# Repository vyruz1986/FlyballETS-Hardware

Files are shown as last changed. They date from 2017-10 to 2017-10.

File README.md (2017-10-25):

## FlyballETS-Hardware

The FlyballETS-Hardware project is a subproject of the [Flyball ETS project](https://www.sparkydevices.com/tag/flyball-ets/).
It contains the designs for the electronic hardware which is required to build the Flyball-ETS project.

## Design Files

The design files are in Eagle format, and consist of several files:
* FlyballETS-Board.sch/brd: Schematic and board file for the PCB of Flyball ETS
* FlyballETS-Board-BOM.txt: Bill of materials used to know which components to order and where to solder them on the board

These files can be used by people who want to improve or change the design.

## Export Files
`Exports/FlyballETS-Board-BRD/SCH.png` are picture exports of the design files so people can view them without needing to install EAGLE

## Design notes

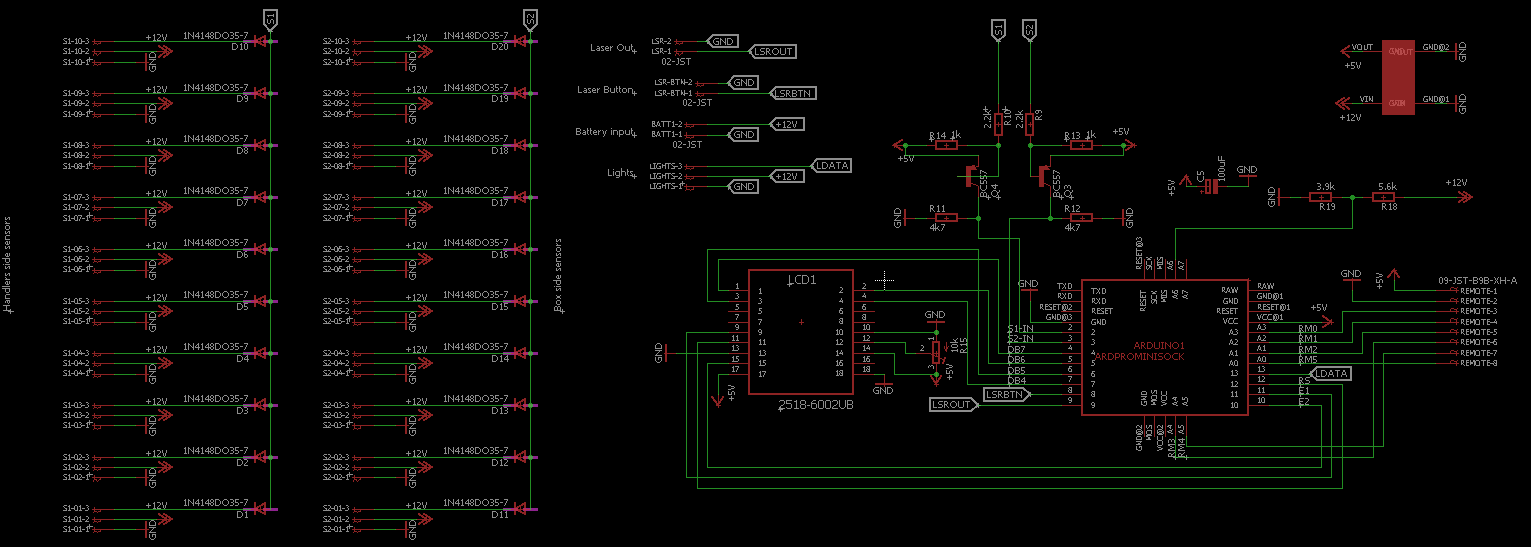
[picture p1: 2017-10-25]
Exports/FlyballETS-Board-SCH.png

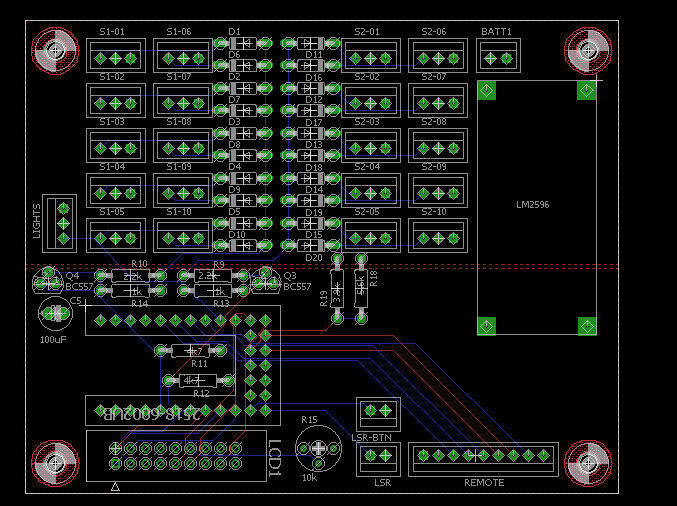
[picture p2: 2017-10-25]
Exports/FlyballETS-Board-BRD.png

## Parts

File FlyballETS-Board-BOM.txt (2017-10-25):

Partlist exported from C:/Workspaces/personal/FlyballETS-Hardware/FlyballETS-Board.sch at 25/10/2017 10:56

Part     Value           Device          Package        Description                          
ARDUINO1 ARDPROMINISOCK  ARDPROMINISOCK  ARDPROMINISOCK                                      
BATT1    02-JST          02-JST          B2B-XH         JST CONNECTOR                        
C5       100uF           CPOL-EUE2,5-6E  E2,5-6E        POLARIZED CAPACITOR, European symbol 
D1       1N4148DO35-7    1N4148DO35-7    DO35-7         DIODE                                
D2       1N4148DO35-7    1N4148DO35-7    DO35-7         DIODE                                
D3       1N4148DO35-7    1N4148DO35-7    DO35-7         DIODE                                
D4       1N4148DO35-7    1N4148DO35-7    DO35-7         DIODE                                
D5       1N4148DO35-7    1N4148DO35-7    DO35-7         DIODE                                
D6       1N4148DO35-7    1N4148DO35-7    DO35-7         DIODE                                
D7       1N4148DO35-7    1N4148DO35-7    DO35-7         DIODE                                
D8       1N4148DO35-7    1N4148DO35-7    DO35-7         DIODE                                
D9       1N4148DO35-7    1N4148DO35-7    DO35-7         DIODE                                
D10      1N4148DO35-7    1N4148DO35-7    DO35-7         DIODE                                
D11      1N4148DO35-7    1N4148DO35-7    DO35-7         DIODE                                
D12      1N4148DO35-7    1N4148DO35-7    DO35-7         DIODE                                
D13      1N4148DO35-7    1N4148DO35-7    DO35-7         DIODE                                
D14      1N4148DO35-7    1N4148DO35-7    DO35-7         DIODE                                
D15      1N4148DO35-7    1N4148DO35-7    DO35-7         DIODE                                
D16      1N4148DO35-7    1N4148DO35-7    DO35-7         DIODE                                
D17      1N4148DO35-7    1N4148DO35-7    DO35-7         DIODE                                
D18      1N4148DO35-7    1N4148DO35-7    DO35-7         DIODE                                
D19      1N4148DO35-7    1N4148DO35-7    DO35-7         DIODE                                
D20      1N4148DO35-7    1N4148DO35-7    DO35-7         DIODE                                
LCD1     2518-6002UB     2518-6002UB     3M_2518-6002UB                                      
LIGHTS   03-JST-B3B-XH-A 03-JST-B3B-XH-A B3B-XH         JST CONNECTOR                        
LSR      02-JST          02-JST          B2B-XH         JST CONNECTOR                        
LSR-BTN  02-JST          02-JST          B2B-XH         JST CONNECTOR                        
Q3       BC557           BC557           TO92           PNP Transistor                       
Q4       BC557           BC557           TO92           PNP Transistor                       
R9       2.2k            R-EU_0207/10    0207/10        RESISTOR, European symbol            
R10      2.2k            R-EU_0207/10    0207/10        RESISTOR, European symbol            
R11      4k7             R-EU_0207/10    0207/10        RESISTOR, European symbol            
R12      4k7             R-EU_0207/10    0207/10        RESISTOR, European symbol            
R13      1k              R-EU_0207/10    0207/10        RESISTOR, European symbol            
R14      1k              R-EU_0207/10    0207/10        RESISTOR, European symbol            
R15      10k             R-TRIMM3339P    RTRIM3339P     Trimm resistor                       
R18      5.6k            R-EU_0207/10    0207/10        RESISTOR, European symbol            
R19      3.9k            R-EU_0207/10    0207/10        RESISTOR, European symbol            
REMOTE   09-JST-B9B-XH-A 09-JST-B9B-XH-A B9B-XH         JST CONNECTOR                        
S1-01    03-JST-B3B-XH-A 03-JST-B3B-XH-A B3B-XH         JST CONNECTOR                        
S1-02    03-JST-B3B-XH-A 03-JST-B3B-XH-A B3B-XH         JST CONNECTOR                        
S1-03    03-JST-B3B-XH-A 03-JST-B3B-XH-A B3B-XH         JST CONNECTOR                        
S1-04    03-JST-B3B-XH-A 03-JST-B3B-XH-A B3B-XH         JST CONNECTOR                        
S1-05    03-JST-B3B-XH-A 03-JST-B3B-XH-A B3B-XH         JST CONNECTOR                        
S1-06    03-JST-B3B-XH-A 03-JST-B3B-XH-A B3B-XH         JST CONNECTOR                        
S1-07    03-JST-B3B-XH-A 03-JST-B3B-XH-A B3B-XH         JST CONNECTOR                        
S1-08    03-JST-B3B-XH-A 03-JST-B3B-XH-A B3B-XH         JST CONNECTOR                        
S1-09    03-JST-B3B-XH-A 03-JST-B3B-XH-A B3B-XH         JST CONNECTOR                        
S1-10    03-JST-B3B-XH-A 03-JST-B3B-XH-A B3B-XH         JST CONNECTOR                        
S2-01    03-JST-B3B-XH-A 03-JST-B3B-XH-A B3B-XH         JST CONNECTOR                        
S2-02    03-JST-B3B-XH-A 03-JST-B3B-XH-A B3B-XH         JST CONNECTOR                        
S2-03    03-JST-B3B-XH-A 03-JST-B3B-XH-A B3B-XH         JST CONNECTOR                        
S2-04    03-JST-B3B-XH-A 03-JST-B3B-XH-A B3B-XH         JST CONNECTOR                        
S2-05    03-JST-B3B-XH-A 03-JST-B3B-XH-A B3B-XH         JST CONNECTOR                        
S2-06    03-JST-B3B-XH-A 03-JST-B3B-XH-A B3B-XH         JST CONNECTOR                        
S2-07    03-JST-B3B-XH-A 03-JST-B3B-XH-A B3B-XH         JST CONNECTOR                        
S2-08    03-JST-B3B-XH-A 03-JST-B3B-XH-A B3B-XH         JST CONNECTOR                        
S2-09    03-JST-B3B-XH-A 03-JST-B3B-XH-A B3B-XH         JST CONNECTOR                        
S2-10    03-JST-B3B-XH-A 03-JST-B3B-XH-A B3B-XH         JST CONNECTOR                        
U$2      LM2596-BOARD    LM2596-BOARD    LM2596-BOARD

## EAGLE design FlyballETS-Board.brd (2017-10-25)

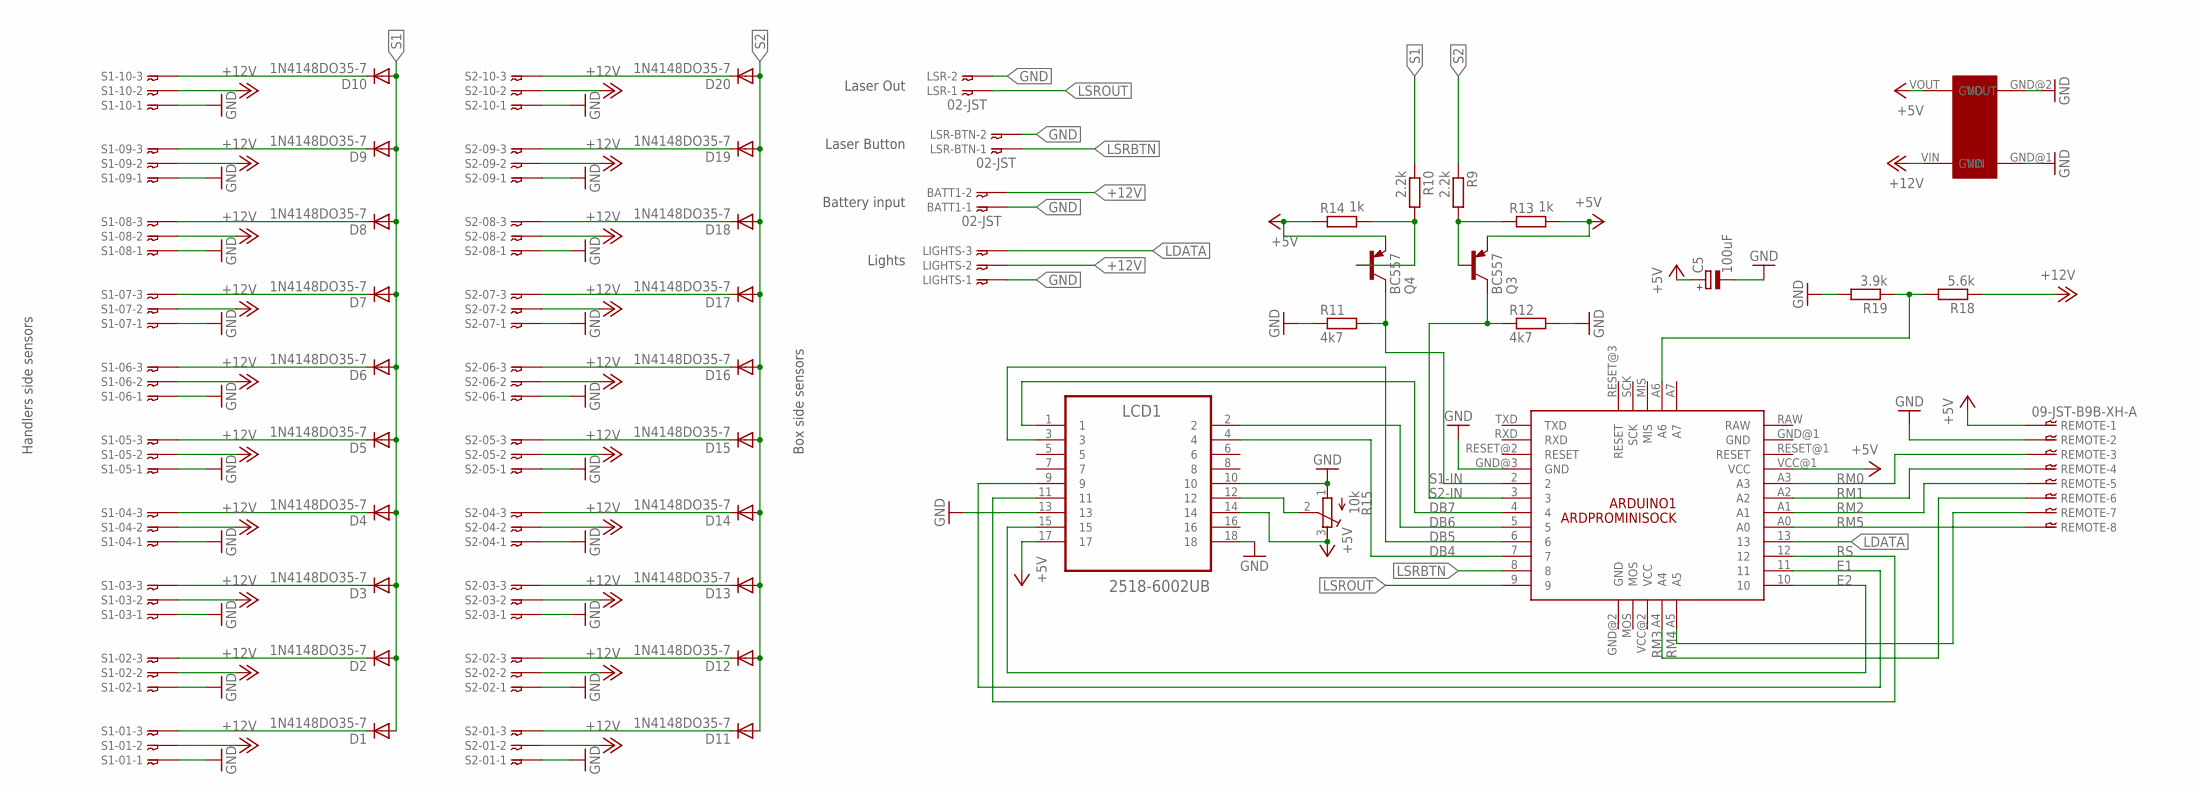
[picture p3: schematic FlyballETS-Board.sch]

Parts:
ARDUINO1: ARDPROMINISOCK
BATT1: 02-JST; B2B-XH
C5: 100uF; E2,5-6E
D1, D2, D3, D4, D5, D6, D7, D8, D9, D10, D11, D12, D13, D14, D15, D16, D17, D18, D19, D20: 1N4148DO35-7; DO35-7
LCD1: 2518-6002UB; 3M_2518-6002UB
LIGHTS: 03-JST-B3B-XH-A; B3B-XH
LSR: 02-JST; B2B-XH
LSR-BTN: 02-JST; B2B-XH
Q3, Q4: BC557; TO92
R9, R10: 2.2k; 0207/10
R11, R12: 4k7; 0207/10
R13, R14: 1k; 0207/10
R15: 10k; RTRIM3339P
R18: 5.6k; 0207/10
R19: 3.9k; 0207/10
REMOTE: 09-JST-B9B-XH-A; B9B-XH
S1-01, S1-02, S1-03, S1-04, S1-05, S1-06, S1-07, S1-08, S1-09, S1-10, S2-01, S2-02, S2-03, S2-04, S2-05, S2-06, S2-07, S2-08, S2-09, S2-10: 03-JST-B3B-XH-A; B3B-XH
U$2: LM2596-BOARD

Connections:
+5V: ARDUINO1.VCC@1 (VCC), C5.+, LCD1.14, LCD1.17, Q3.1 (E), Q4.1 (E), R13.2, R14.1, R15.3 (E), REMOTE.P$1, U$2.VOUT
+12V: BATT1.P$2, LIGHTS.P$2, R18.1, S1-01.P$2, S1-02.P$2, S1-03.P$2, S1-04.P$2, S1-05.P$2, S1-06.P$2, S1-07.P$2, S1-08.P$2, S1-09.P$2, S1-10.P$2, S2-01.P$2, S2-02.P$2, S2-03.P$2, S2-04.P$2, S2-05.P$2, S2-06.P$2, S2-07.P$2, S2-08.P$2, S2-09.P$2, S2-10.P$2, U$2.VIN
DB4: ARDUINO1.7, LCD1.4
DB5: ARDUINO1.6, LCD1.3
DB6: ARDUINO1.5, LCD1.2
DB7: ARDUINO1.4, LCD1.1
E1: ARDUINO1.11, LCD1.9
E2: ARDUINO1.10, LCD1.15
GND: ARDUINO1.GND@3 (GND), BATT1.P$1, C5.-, LCD1.10, LCD1.13, LCD1.18, LIGHTS.P$1, LSR.P$2, LSR-BTN.P$2, R11.1, R12.2, R15.1 (A), R19.2, REMOTE.P$2, S1-01.P$1, S1-02.P$1, S1-03.P$1, S1-04.P$1, S1-05.P$1, S1-06.P$1, S1-07.P$1, S1-08.P$1, S1-09.P$1, S1-10.P$1, S2-01.P$1, S2-02.P$1, S2-03.P$1, S2-04.P$1, S2-05.P$1, S2-06.P$1, S2-07.P$1, S2-08.P$1, S2-09.P$1, S2-10.P$1, U$2.GND@1 (GND), U$2.GND@2 (GND)
LDATA: ARDUINO1.13, LIGHTS.P$3
LSRBTN: ARDUINO1.8, LSR-BTN.P$1
LSROUT: ARDUINO1.9, LSR.P$1
unnamed: Q3.2 (B), R9.2, R13.1
unnamed: Q4.2 (B), R10.2, R14.2
unnamed: LCD1.12, R15.2 (S)
unnamed: D10.C, S1-10.P$3
unnamed: D9.C, S1-09.P$3
unnamed: D8.C, S1-08.P$3
unnamed: D7.C, S1-07.P$3
unnamed: D6.C, S1-06.P$3
unnamed: D5.C, S1-05.P$3
unnamed: D4.C, S1-04.P$3
unnamed: D3.C, S1-03.P$3
unnamed: D2.C, S1-02.P$3
unnamed: D1.C, S1-01.P$3
unnamed: D20.C, S2-10.P$3
unnamed: D19.C, S2-09.P$3
unnamed: D18.C, S2-08.P$3
unnamed: D17.C, S2-07.P$3
unnamed: D16.C, S2-06.P$3
unnamed: D15.C, S2-05.P$3
unnamed: D14.C, S2-04.P$3
unnamed: D13.C, S2-03.P$3
unnamed: D12.C, S2-02.P$3
unnamed: D11.C, S2-01.P$3
RM0: ARDUINO1.A3, REMOTE.P$3
RM1: ARDUINO1.A2, REMOTE.P$4
RM2: ARDUINO1.A1, REMOTE.P$5
RM3: ARDUINO1.A4, REMOTE.P$6
RM4: ARDUINO1.A5, REMOTE.P$7
RM5: ARDUINO1.A0, REMOTE.P$8
RS: ARDUINO1.12, LCD1.11
S1: D1.A, D2.A, D3.A, D4.A, D5.A, D6.A, D7.A, D8.A, D9.A, D10.A, R10.1
S1-IN: ARDUINO1.2, Q4.3 (C), R11.2
S2: D11.A, D12.A, D13.A, D14.A, D15.A, D16.A, D17.A, D18.A, D19.A, D20.A, R9.1
S2-IN: ARDUINO1.3, Q3.3 (C), R12.1
VSENS: ARDUINO1.A6, R18.2, R19.1

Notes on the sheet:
Battery input
Handlers side sensors
Box side sensors
Laser Out
Laser Button
Lights

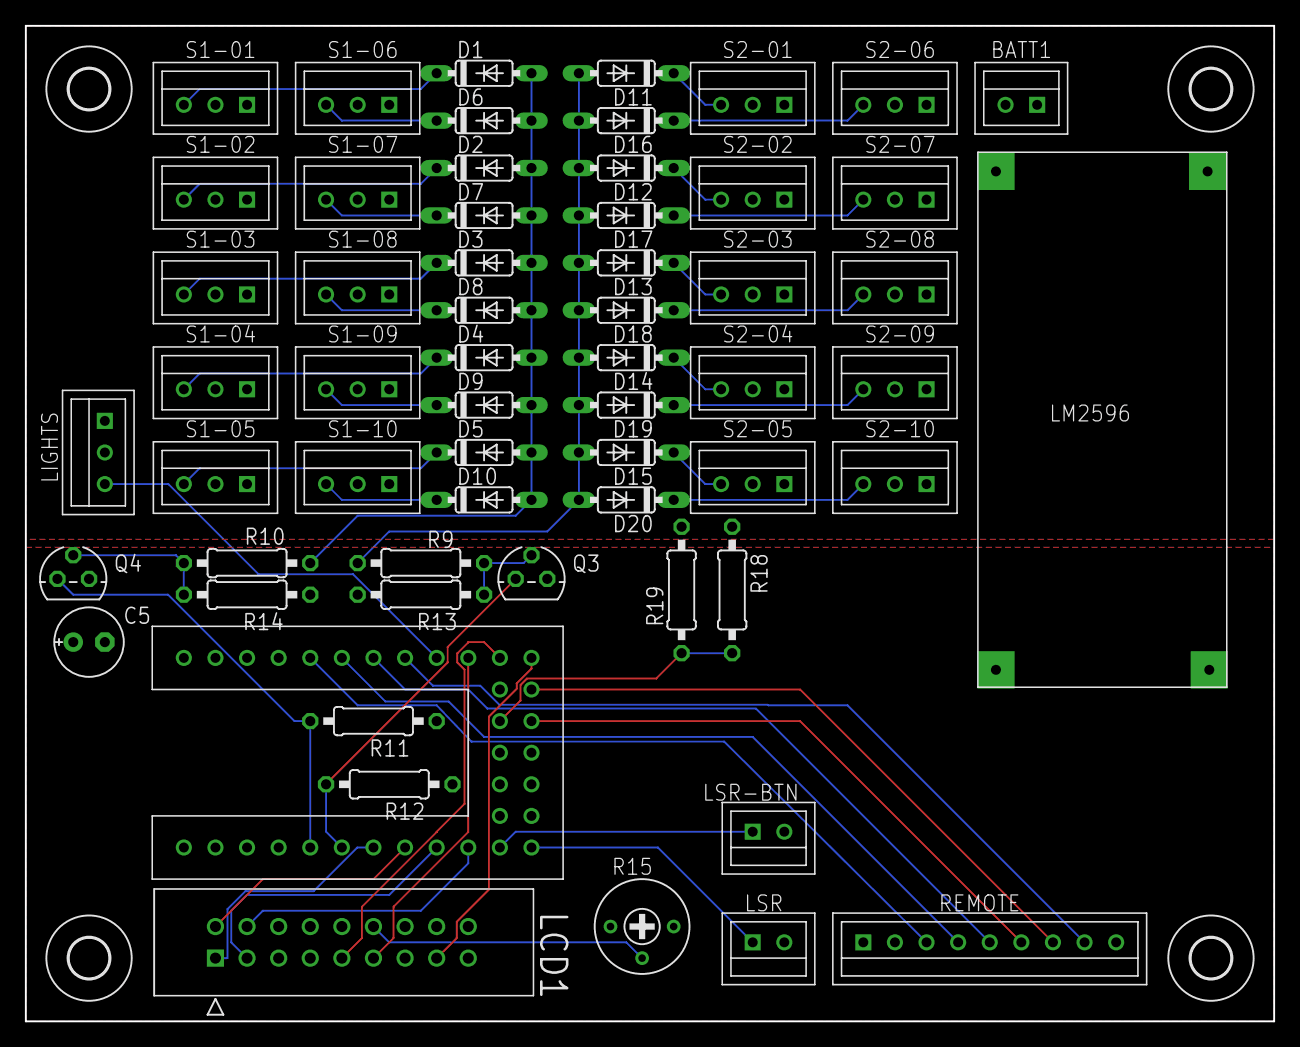
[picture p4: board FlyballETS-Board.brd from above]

Board: 2 copper layers, 100.3 x 80.0 mm, 64 parts (0 on the bottom side), 47 nets.

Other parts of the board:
U$1, U$3, U$4, U$5: 3,2

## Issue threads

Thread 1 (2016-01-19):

Screw holes are too close to components

vyruz1986, 2016-01-19:
Seen on:
- Mainboard v1:
  - Near LCD connector
  - Near PWR connector

All layouts should be checked to allow for 5mm screw heads around 3mm holes

Closed 2017-08-12.

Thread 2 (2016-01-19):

Resistor values on PowerBoard are not practical

vyruz1986, 2016-01-19:
The PowerBoard R1 and R2 resistors are used to create a voltage divider from the 12.6 V from the battery to 5V which is safe to be measured by the arduino.
Current values 70k and 50k are theoretically correct, but these are not standard resistor values.
Changing them to R1=5.6K and R2=3.9k also works and are practical since these values are available in most resistor assortments

Closed 2017-08-12.

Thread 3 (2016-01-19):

Pin numbering between power board and lights board is wrong

vyruz1986, 2016-01-19:
On power board, the LIGHTS connector has the following pin out:
- 1: GND
- 2: +12V
- 3: + 5V

While the lights board has the following pin out for the PWR connector:
- 1: GND
- 2: +5V
- 3: +12V

Can easily be worked around by swapping pins on  the cable, but would be better to use same pin numbering

Closed 2017-08-12.

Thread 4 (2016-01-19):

Pin numbering on JST-XH connectors is reversed

vyruz1986, 2016-01-19:
The library used for the JST-XH connectors seems to have reversed pin numbering.
Looking at the datasheet of the JST-XH connector (http://www.farnell.com/datasheets/5448.pdf) one can see that the cable-side (female?) connector has a small notch carved out to mark pin number one.
This pin number however is on the opposite side of where pin number one on the PCB for the PCB-side (male?) connector is marked.

Workaround is to rotate PCB connectors 180 degrees, but then they don't align with outline drawn in silk layer anymore, and could end up overlapping other lables or screw holes

Closed 2017-08-12.

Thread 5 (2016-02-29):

LightsBoard: Issues with 74HC595

vyruz1986, 2016-02-29:
- No decoupling capacitor present, add 100nF cap over VCC(p8) and GND(p16)
- MR (p10) is not connected to VCC, results in almost non-working lightsboard

Closed 2016-03-02.

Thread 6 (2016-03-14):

Lightsboard: Pin numbers on Lx-x connectors are reversed

vyruz1986, 2016-03-14:
The pin numbering on L2 side is reversed!

vyruz1986, 2016-03-14:
This was fixed in 756da387ae336f8f76a98ecb6b904a8d5f60ef0c

Closed 2016-03-14.

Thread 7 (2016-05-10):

Light colors should be marked on PCB

vyruz1986, 2016-05-10:
Currently only lights 1-5 are numbered on the PCB, however it's not clear which color goes where.
It would be better to add color names to the PCB silk screen and schematic.

Closed 2017-08-12.

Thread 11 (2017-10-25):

ESP32 board prototype: BC557 seems to be wrong footprint

vyruz1986, 2017-10-25:
Should be TO-92 wide instead of TO-92 narrow

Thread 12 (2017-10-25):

ESP32 board prototype: No connector for sensor LEDs

vyruz1986, 2017-10-25:
There should be a connector to connect LED's which represent the state of both sensor columns

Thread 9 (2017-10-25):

ESP32 board prototype: Final DRC was not run, copper planes wrong

vyruz1986, 2017-10-25:
I forgot to run a final DRC before ordering the boards, this resulted in copper planes running over the GPS connector traces

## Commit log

2015-08-30 Cleaned up mainboard design
    [FlyballETS-MBD.brd, FlyballETS-MBD.sch]
2015-08-31 Added power board files
    [FlyballETS-PWR.brd, FlyballETS-PWR.sch]
2015-09-01 Updated readme to include PWR board description
2015-09-01 Updated drawings and added PNG exports
    - Added frames around drawings to make it look neater
    - Added PNG export files so people who don't have EAGLE can see
    everything
    [FlyballETS-LIGHTS.brd, FlyballETS-LIGHTS.sch, FlyballETS-MBD.brd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]
2015-09-05 Corrected unrouted airwire
    The SensorsBoard had an unrouted airwire, this has been corrected
    [FlyballETS-SENSORS.brd]
2015-12-20 Mainboard v2
    - Changed connectors to use JST-XH type
    - For LCD screen use flatcable/ribboncable connector (2x9 pins)
    - Repositioned everything to allow for smaller board size (12% smaller)
    [FlyballETS-MBD.brd, FlyballETS-MBD.sch]
2015-12-30 Minor updates + added BOMs
    - Updated to EAGLE 7.5.0
    - Added BOM text file exports
    - Renamed arduino socket on MBD board
    [FlyballETS-MBD.brd, FlyballETS-MBD.sch]
2015-12-30 Incorrect capacitor value
    Changed 100nF to 100uF
    [FlyballETS-MBD.brd, FlyballETS-MBD.sch]
2016-01-10 v2 release of remaining boards.
    - Lightsboard: Corrected swapped pin connections on L2 side and made
    smaller
    - Powerboard: Made smaller and added descriptions for LM2596 board
    - Sensorboard: Made smaller
    - All boards: Removed JST connector type names
    [FlyballETS-LIGHTS.brd, FlyballETS-LIGHTS.sch, FlyballETS-PWR.brd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]
2016-03-02 LightsBoard:Fix 74HC595 problems
    Closes #5
    - Added decoupling capacitor over GND and VCC of 74HC595
    - Added missing connection of 74HC595 pin10 to +5V
    [FlyballETS-LIGHTS.brd, FlyballETS-LIGHTS.sch]
2016-03-13 Changed resistor values to more practical ones
    Changed R1 to 5.6kOhm, R2 to 3.9kOhm. These are common values in
    resistor assortments. Fixes #2
    [FlyballETS-PWR.brd, FlyballETS-PWR.sch]
2016-05-10 Fixed several issues
    - Checked all mounting holes (fixes #1 )
    - Marked light colors on lights PCB (fixes #7 )
    - Swapped pins 2 and 3 on LIGHTS connected on PWR board (fixes #3 )
    [FlyballETS-LIGHTS.brd, FlyballETS-LIGHTS.sch, FlyballETS-PWR.brd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]
2017-08-12 Fixed JST XH pin numbering
    Updated bt_con-jst-xh.lbr library with swapped pin numbering.
    Updated all board designs with updated library so they have the
    connectors the right way around
    Fixes #4
    [FlyballETS-LIGHTS.brd, FlyballETS-LIGHTS.sch, FlyballETS-MBD.brd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]
2017-08-23 Added one board to rule them all :)
    [FlyballETS-Board.brd, FlyballETS-Board.sch]
2017-10-25 Final changes for v4 release
    - Corrected README
    - Removed obsolete schematics, boards and export pictures
    - Added export for schematic
    [FlyballETS-LIGHTS.brd, FlyballETS-LIGHTS.sch, FlyballETS-MBD.brd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]

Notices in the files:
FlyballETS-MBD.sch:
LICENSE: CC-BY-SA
